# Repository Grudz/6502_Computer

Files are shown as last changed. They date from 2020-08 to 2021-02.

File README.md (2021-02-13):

# 6502_Computer
This repository stores everything for my 6502 project. This includes schematics, datasheets, C scripts, and assembly programs
.
[Ben Eater](https://www.youtube.com/playlist?list=PLowKtXNTBypFbtuVMUVXNR0z1mu7dp7eH) designed a custom clock module and 6502 computer on a breadboard. I expanded on that project, by combining those and turning them into a PCB.

-----
### Pretty dope red PCB I designed (4 layers:wink:)



### My Breadboard, not too shabby:sunglasses:

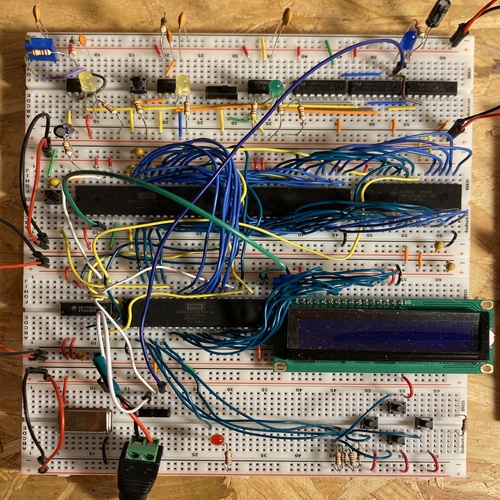
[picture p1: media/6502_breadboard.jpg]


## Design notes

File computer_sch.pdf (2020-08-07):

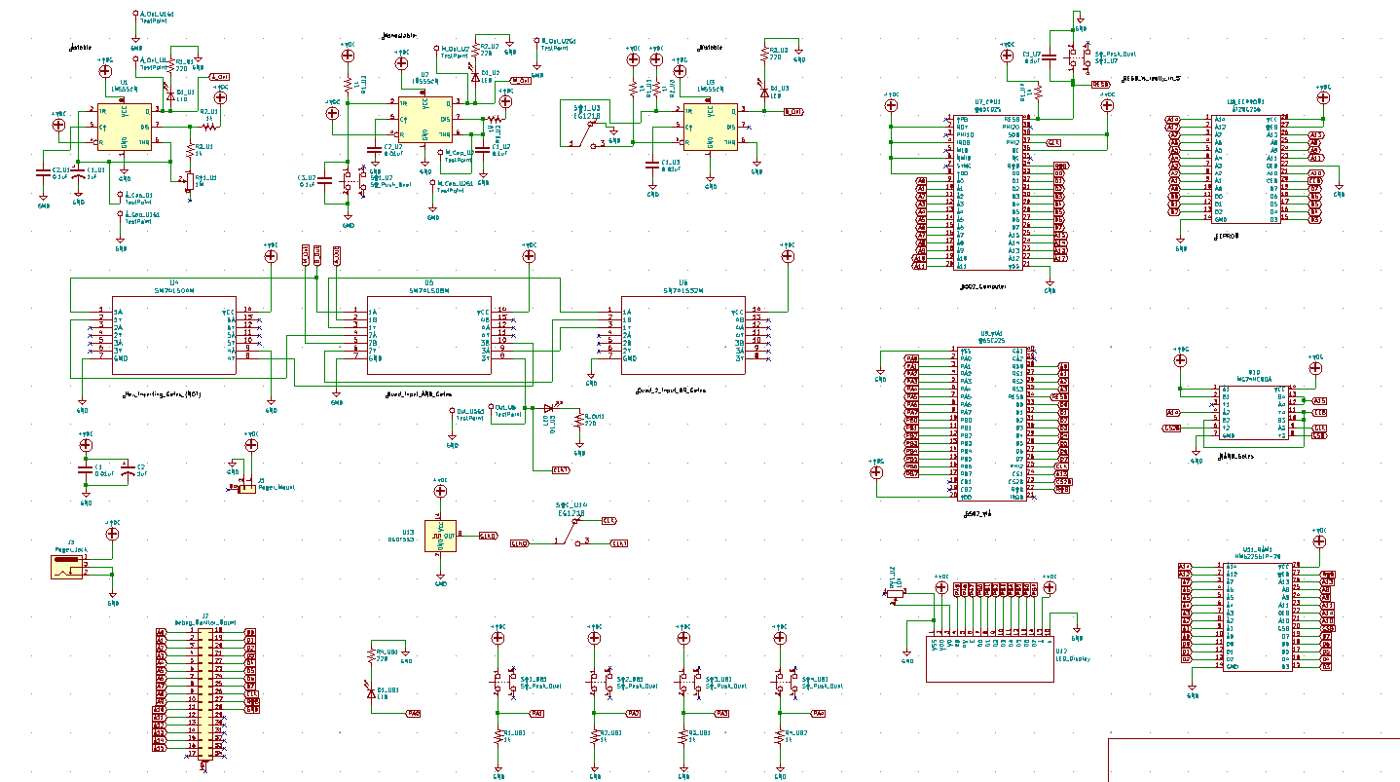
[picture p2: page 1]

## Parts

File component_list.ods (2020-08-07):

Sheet: Clock
Component | Package | Price [$] | Ordered | Delivered | Min Quantity | Footprint | Link to purchase
Ceramic Cap | THT | 17 | Yes | Yes | 5 | 157 | https://www.amazon.com/Hilitchi-Monolithic-Multilayer-Capacitors-Assortment/dp/B071P44QBH
Electrolytic Cap | THT | 15 | Yes | Yes | 1 | 59 | https://www.amazon.com/OCR-Electrolytic-Capacitor-Assortment-0-1uF%EF%BC%8D1000uF/dp/B01MSQOX0Q
Resistor | 1206 – SMD | 8 | Yes | Yes | 9 | 15 | https://www.amazon.com/McIgIcM-Resistor-ohm-10-Assorted-Samples/dp/B06XD8HPXS
Tactile Button | N/A | 0 | N/A | N/A | 1 | 87 | N/A
Switch | N/A | 3 | Yes | Yes | 1 | Custom | https://www.digikey.com/product-detail/en/EG1218/EG1903-ND/101726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
1M Pot | N/A | 10 | Yes | Yes | 1 | 39 | https://www.amazon.com/Twidec-Multiturn-Potentiometer-Assortment-3296W-13/dp/B07PYSR8SF
LED | N/A | 0 | N/A | N/A | 4 | 17 | N/A
SN74LS04 | N/A | 3 | Yes | Yes | 1 | Custom | https://www.mouser.com/ProductDetail/Texas-Instruments/SN74LS04N?qs=spW5eSrOWB4DgGWIHPxzvg%3D%3D
SN74LS08 | N/A | 12 | Yes | Yes | 1 | Custom | https://www.amazon.com/SN74LS08N-SN74LS08-74LS08N-HD74LS08P-Original/dp/B07KPMXX4P
SN74LS32 | N/A | 3 | Yes | Yes | 1 | Custom | https://www.mouser.com/ProductDetail/Texas-Instruments/SN74LS32N?qs=q2XTDbzbm6DA9Mnew5GiLA%3D%3D
LM555CN | N/A | 3 | Yes | Yes | 3 | 30 | https://www.parts-express.com/lm555-timer-ic-(8-pin-dip)--lm555 | have confirmation email from “contact”. It’s been 10 days, call tomorrow the 23rd
Test Point | N/A | 10 | Yes | Yes | 6 | 12 | https://www.digikey.com/product-detail/en/keystone-electronics/5000/36-5000-ND/255326 | https://www.digikey.com/product-detail/en/keystone-electronics/5001/36-5001-ND/255327 | https://www.digikey.com/product-detail/en/keystone-electronics/5002/36-5002-ND/255328 | https://www.digikey.com/product-detail/en/keystone-electronics/5004/36-5004-ND/362669 | https://www.digikey.com/product-detail/en/keystone-electronics/5003/36-5003-ND/362668
DIP Sockets | N/A | 11 | Yes | Yes | 6 | Same Footprint | https://www.amazon.com/Glarks-122Pcs-Sockets-Adaptor-Assortment/dp/B01GOLSUAU
 |  |  |  |  |  |  |  | PCB holder | To-Do List
 |  |  |  |  |  |  |  | https://www.amazon.com/Aven-17010-Adjustable-Circuit-Holder/dp/B00Q2TTQEE?s=industrial | Add areas to prop PCB off the ground
PCB |  |  |  |  |  |  |  | $10.00 | Ordered
Ordered on JLC PCB, should arrive by Friday unless unexpected delays
Cost $23 |  |  |  |  |  |  |  | TOTAL
 |  |  |  |  |  |  |  | 140ish

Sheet: Computer
Component | Package | Price [$] | Ordered | Delivered | Quantity | Footprint | Link to purchase
Ceramic Cap | THT | 17 | N/A | N/A | 5 | 157 | https://www.amazon.com/Hilitchi-Monolithic-Multilayer-Capacitors-Assortment/dp/B071P44QBH
Electrolytic Cap | THT | 15 | N/A | N/A | 1 | 59 | https://www.amazon.com/OCR-Electrolytic-Capacitor-Assortment-0-1uF%EF%BC%8D1000uF/dp/B01MSQOX0Q
Resistor | 1206 – SMD | 8 | N/A | N/A | 9 | 15 | https://www.amazon.com/McIgIcM-Resistor-ohm-10-Assorted-Samples/dp/B06XD8HPXS
Tactile Button | N/A | 0 | N/A | N/A | 1 | 87 | N/A
Switch | N/A | 3 | N/A | N/A | 1 | Custom | https://www.digikey.com/product-detail/en/EG1218/EG1903-ND/101726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
1M/10k Pot | N/A | 10 | N/A | N/A | 1 | 39 | https://www.amazon.com/Twidec-Multiturn-Potentiometer-Assortment-3296W-13/dp/B07PYSR8SF
LED | N/A | 0 | N/A | N/A | 4 | 17 | N/A
SN74LS04 | N/A | 3 | N/A | N/A | 1 | Custom | https://www.mouser.com/ProductDetail/Texas-Instruments/SN74LS04N?qs=spW5eSrOWB4DgGWIHPxzvg%3D%3D
SN74LS08 | N/A | 12 | N/A | N/A | 1 | Custom | https://www.amazon.com/SN74LS08N-SN74LS08-74LS08N-HD74LS08P-Original/dp/B07KPMXX4P
SN74LS32 | N/A | 3 | N/A | N/A | 1 | Custom | https://www.mouser.com/ProductDetail/Texas-Instruments/SN74LS32N?qs=q2XTDbzbm6DA9Mnew5GiLA%3D%3D
LM555CN | N/A | 3 | N/A | N/A | 3 | 30 | https://www.parts-express.com/lm555-timer-ic-(8-pin-dip)--lm555
Test Point | N/A | 10 | N/A | N/A | 6 | 12 | https://www.digikey.com/product-detail/en/keystone-electronics/5000/36-5000-ND/255326 | https://www.digikey.com/product-detail/en/keystone-electronics/5001/36-5001-ND/255327 | https://www.digikey.com/product-detail/en/keystone-electronics/5002/36-5002-ND/255328 | https://www.digikey.com/product-detail/en/keystone-electronics/5004/36-5004-ND/362669 | https://www.digikey.com/product-detail/en/keystone-electronics/5003/36-5003-ND/362668
DIP Sockets | N/A | 11 | N/A | N/A | 6 | Same Footprint | https://www.amazon.com/Glarks-122Pcs-Sockets-Adaptor-Assortment/dp/B01GOLSUAU
74HC00 | N/A | 5 | yes | yes | 10 | Same as other logic | https://www.jameco.com/webapp/wcs/stores/servlet/ProductDisplay?productId=45161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
W65C02S | N/A | 14 | yes | yes | 2 | 134 | https://www.jameco.com/z/W65C02S6TPG-14-Western-Design-Center-MPU-8-Bit-14MHz-65KB-Memory-40-Pin-PDIP_2143638.html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
W65C22 | N/A | 14 | yes | yes | 2 | 134 | https://www.jameco.com/webapp/wcs/stores/servlet/ProductDisplay?productId=2143591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
AT28C256 | N/A | 14 | yes | yes | 2 | 121 | https://www.jameco.com/webapp/wcs/stores/servlet/ProductDisplay?productId=74843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
HM62256B | N/A | 8 | yes | yes | 2 | 121 | https://www.jameco.com/webapp/wcs/stores/servlet/ProductDisplay?productId=82472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
1Mhz Clock | N/A | 6 | yes | yes | 3 | 3 | https://www.jameco.com/webapp/wcs/stores/servlet/ProductDisplay?productId=27861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
Rubber Props | N/A | 4 | yes | yes | 1 | N/A | https://www.jameco.com/z/BS34BL12X25RP-Rubber-Feet-Adhesive-Cylindrical-Black-0-375-Inch-x-0-125-Inch-100-Piece-Pack-_2119718.html
Tactile Buttons | N/A | 3 | yes | yes | 10 | Same as above | https://www.jameco.com/webapp/wcs/stores/servlet/ProductDisplay?productId=149948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
Female Headers | 2x34, 2.54mm | 3 | yes | yes | 3 | 208 | https://www.jameco.com/webapp/wcs/stores/servlet/ProductDisplay?productId=163862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
Male Headers | 2 Pin, 2.54mm | 1 | yes | yes | 10 | 4 | https://www.jameco.com/z/7000-1X2SG-R-Connector-Unshrouded-Header-Male-2-Position-0-100-2-54mm-Solder-Straight-Th_108338.html
Power Adapter | 2.5mm | 3 | yes | yes | 5 | 6 | https://www.jameco.com/webapp/wcs/stores/servlet/ProductDisplay?productId=2168122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 |  |  | (Ordered 15.24mm in 28pin dip sockets)
 |  |  |  |  |  |  |  | TOTAL | 120 + PCB
 |  |  |  |  |  |  |  | order number #20659175
 |  |  |  |  |  |  |  | Expected July 17th
PCB |  |  |  |  |  |  |  |  |  |  | Ordered another 2.1mmx5mm power adapter and barrel jack pcb mounts plus some wire for fun
Ordered on JLC PCB, should arrive by Friday unless unexpected delays |  |  |  |  |  |  |  |  |  |  | PCB ordered on July 21st
Cost $23
 |  |  |  |  | need new power adapater, prolly 2.1mm, but consider USBA
 |  |  |  |  | need pcb flux cleaner

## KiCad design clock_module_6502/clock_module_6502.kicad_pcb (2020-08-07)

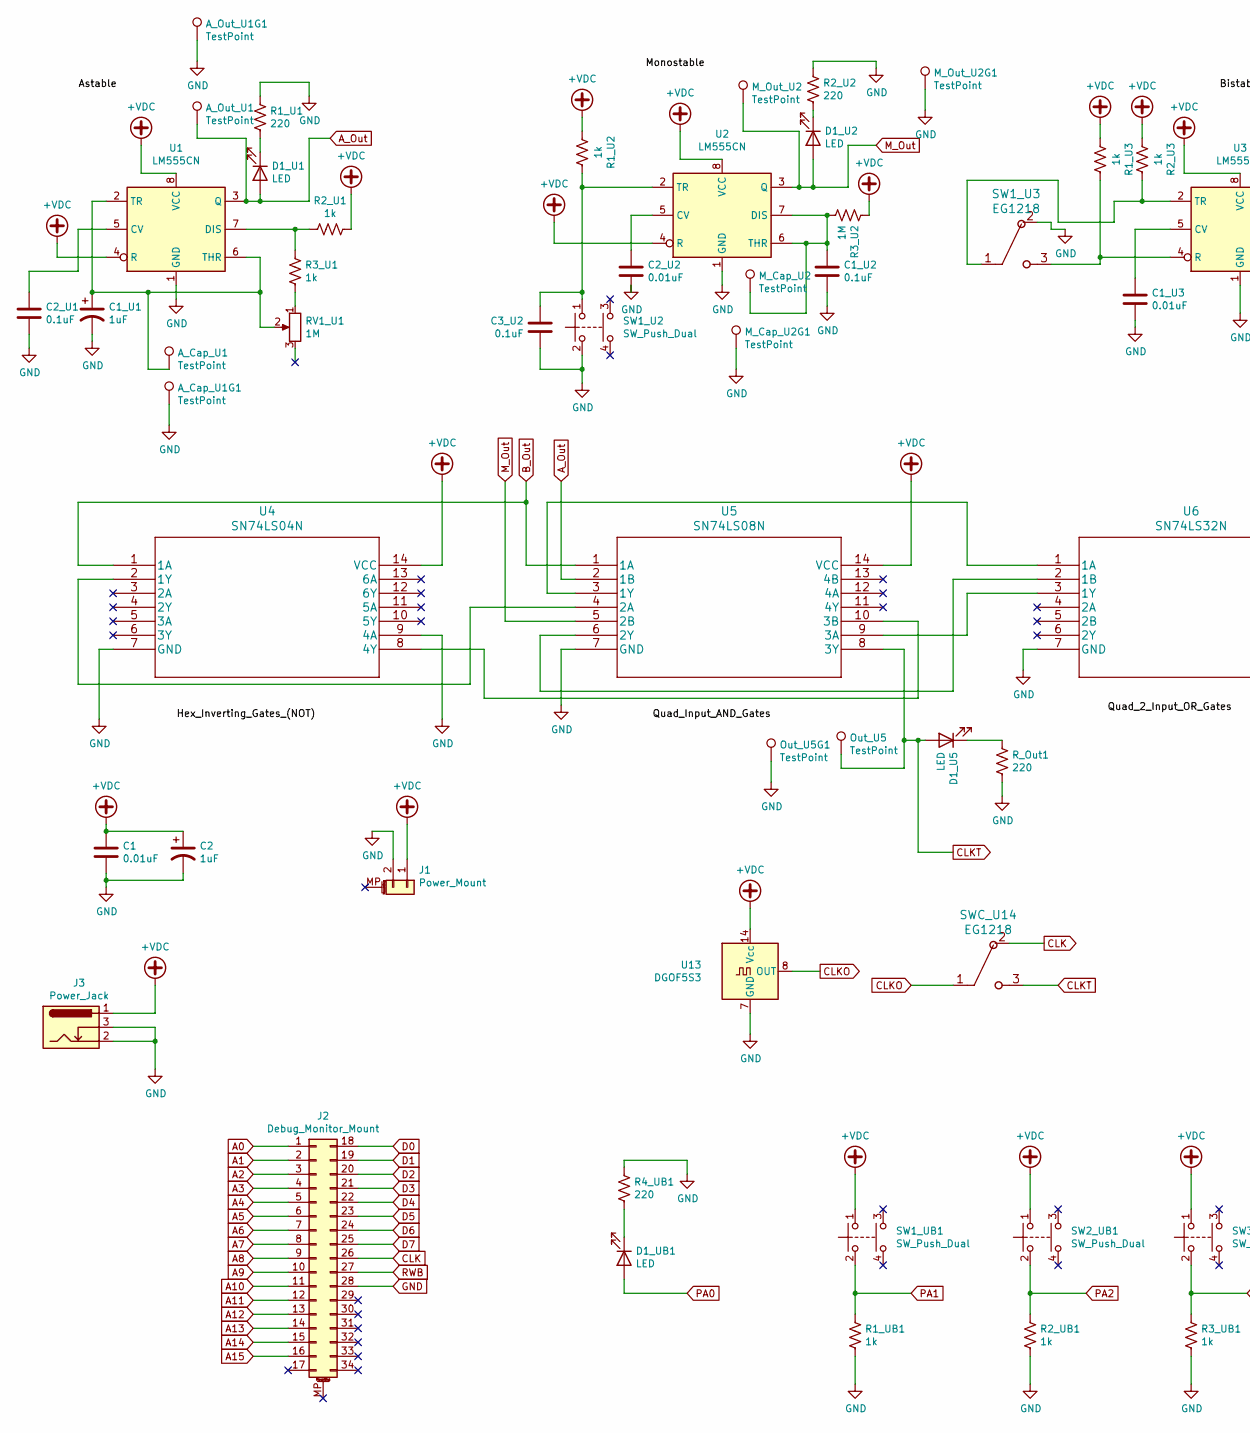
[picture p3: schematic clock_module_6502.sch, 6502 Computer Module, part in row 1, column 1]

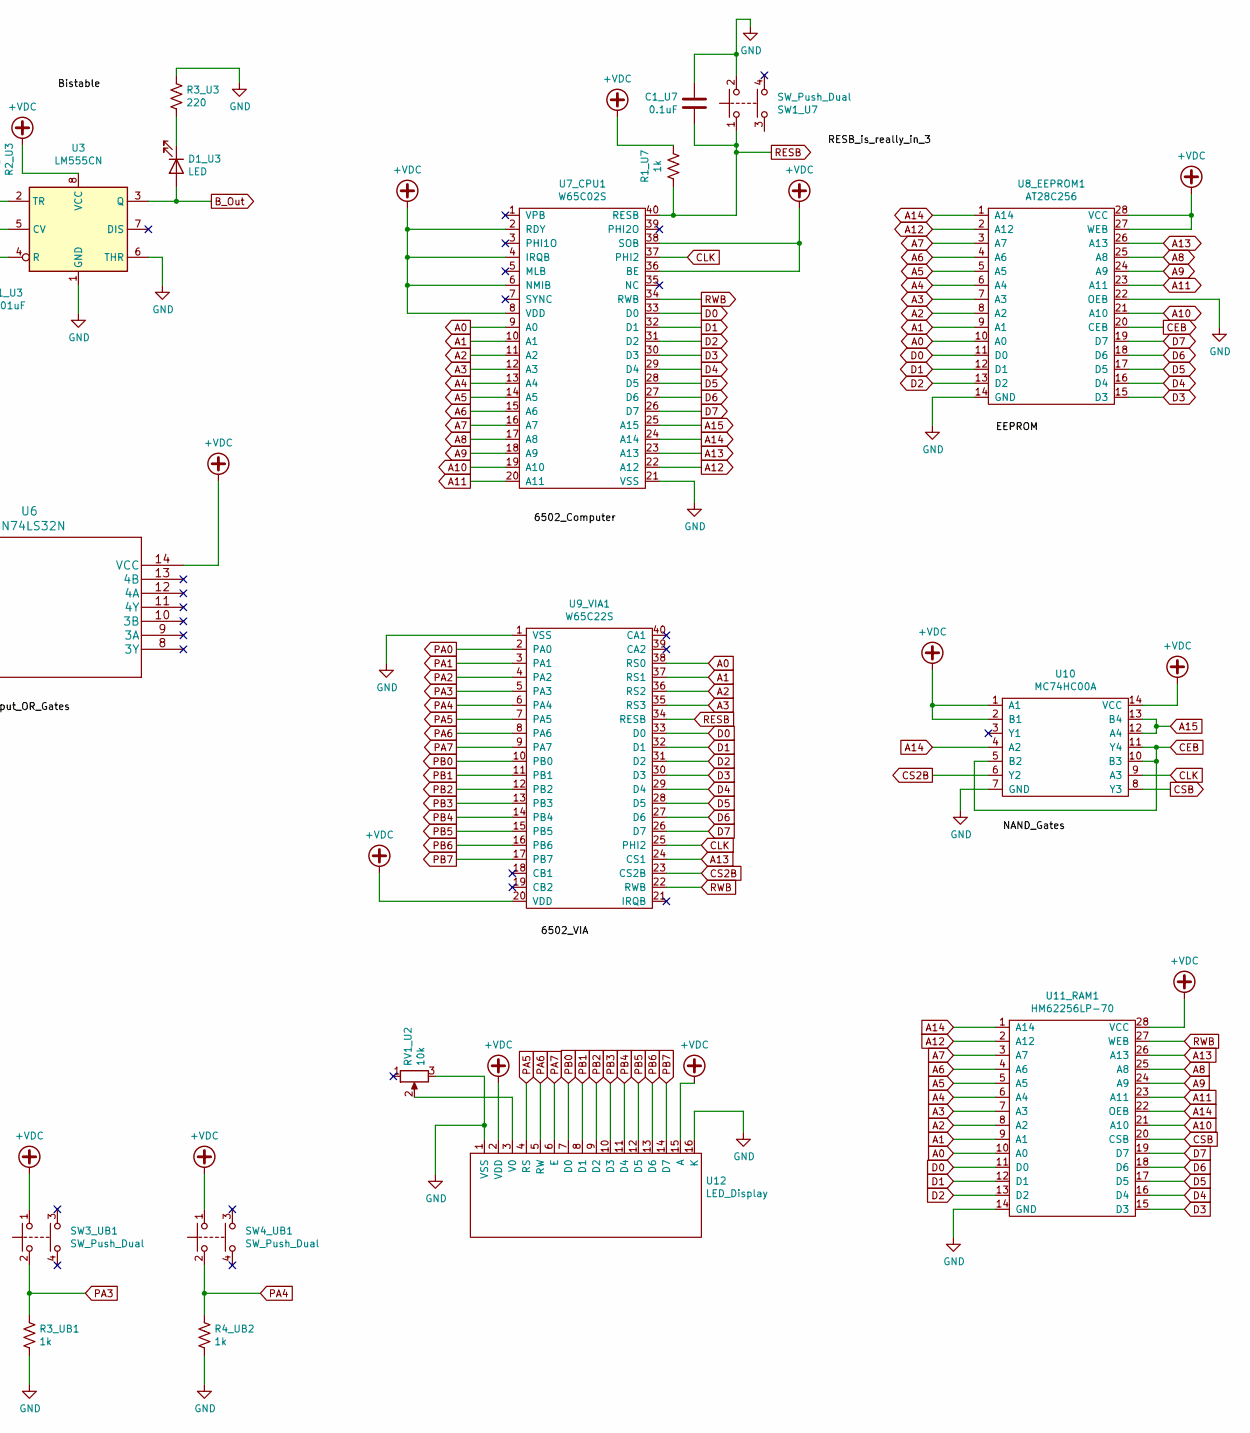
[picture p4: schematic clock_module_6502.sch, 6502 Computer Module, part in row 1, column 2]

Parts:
A_Cap_U1, A_Cap_U1G1: TestPoint; TestPoint_Keystone_5000-5004_Miniature
A_Out_U1, A_Out_U1G1: TestPoint; TestPoint_Keystone_5000-5004_Miniature
C1, C1_U3, C2_U2: 0.01uF; C_Disc_D7.5mm_W5.0mm_P5.00mm
C1_U1, C2: 1uF; CP_Radial_D5.0mm_P2.50mm
C1_U2, C1_U7, C2_U1, C3_U2: 0.1uF; C_Disc_D7.5mm_W5.0mm_P5.00mm
D1_U1, D1_U2, D1_U3, D1_U5, D1_UB1: LED; LED_D3.0mm_FlatTop
J1: Power_Mount; PinHeader_1x02_P2.54mm_Vertical
J2: Debug_Monitor_Mount; PinHeader_2x17_P2.54mm_Vertical
J3: Power_Jack; BarrelJack_Horizontal
M_Cap_U2, M_Cap_U2G1: TestPoint; TestPoint_Keystone_5000-5004_Miniature
M_Out_U2, M_Out_U2G1: TestPoint; TestPoint_Keystone_5000-5004_Miniature
Out_U5, Out_U5G1: TestPoint; TestPoint_Keystone_5000-5004_Miniature
R1_U1, R2_U2, R3_U3, R4_UB1: 220; R_1206_3216Metric_Pad1.42x1.75mm_HandSolder
R1_U2, R1_U3, R1_U7, R1_UB1, R2_U1, R2_U3, R2_UB1, R3_U1, R3_UB1, R4_UB2: 1k; R_1206_3216Metric_Pad1.42x1.75mm_HandSolder
R3_U2: 1M; R_1206_3216Metric_Pad1.42x1.75mm_HandSolder
RV1_U1: 1M; Potentiometer_Bourns_3296W_Vertical
RV1_U2: 10k; Potentiometer_Bourns_3296W_Vertical
R_Out1: 220; R_1206_3216Metric_Pad1.42x1.75mm_HandSolder
SW1_U2, SW1_U7, SW1_UB1, SW2_UB1, SW3_UB1, SW4_UB1: SW_Push_Dual; SW_Tactile_Straight_KSL0Axx1LFTR
SW1_U3: EG1218
SWC_U14: EG1218
U1, U2, U3: LM555CN; DIP-8_W7.62mm
U4: SN74LS04N; SN74LS32N
U5: SN74LS08N; SN74LS32N
U6: SN74LS32N
U7_CPU1: W65C02S; DIP-40_W15.24mm_Socket
U8_EEPROM1: AT28C256; DIP-28_W15.24mm_Socket
U9_VIA1: W65C22S; DIP-40_W15.24mm_Socket
U10: MC74HC00A; SN74LS32N
U11_RAM1: HM62256LP-70; DIP-28_W15.24mm_Socket
U12: LED_Display; WC1602A
U13: DGOF5S3; Oscillator_DIP-14

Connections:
+VDC: C1.1, C2.1, J1.1, J3.1, R1_U2.2, R1_U3.2, R1_U7.1, R2_U1.1, R2_U3.2, R3_U2.2, SW1_UB1.1, SW2_UB1.1, SW3_UB1.1, SW4_UB1.1, U1.4 (R), U1.8 (VCC), U2.4 (R), U2.8 (VCC), U3.8 (VCC), U4.14 (VCC), U5.14 (VCC), U6.14 (VCC), U7_CPU1.2 (RDY), U7_CPU1.4 (IRQB), U7_CPU1.6 (NMIB), U7_CPU1.8 (VDD), U7_CPU1.36 (BE), U7_CPU1.38 (SOB), U8_EEPROM1.27 (WEB), U8_EEPROM1.28 (VCC), U9_VIA1.20 (VDD), U10.1 (A1), U10.2 (B1), U10.14 (VCC), U11_RAM1.28 (VCC), U12.2 (VDD), U12.15 (A), U13.14 (Vcc)
A0: J2.1, U7_CPU1.9 (A0), U8_EEPROM1.10 (A0), U9_VIA1.38 (RS0), U11_RAM1.10 (A0)
A1: J2.2, U7_CPU1.10 (A1), U8_EEPROM1.9 (A1), U9_VIA1.37 (RS1), U11_RAM1.9 (A1)
A2: J2.3, U7_CPU1.11 (A2), U8_EEPROM1.8 (A2), U9_VIA1.36 (RS2), U11_RAM1.8 (A2)
A3: J2.4, U7_CPU1.12 (A3), U8_EEPROM1.7 (A3), U9_VIA1.35 (RS3), U11_RAM1.7 (A3)
A4: J2.5, U7_CPU1.13 (A4), U8_EEPROM1.6 (A4), U11_RAM1.6 (A4)
A5: J2.6, U7_CPU1.14 (A5), U8_EEPROM1.5 (A5), U11_RAM1.5 (A5)
A6: J2.7, U7_CPU1.15 (A6), U8_EEPROM1.4 (A6), U11_RAM1.4 (A6)
A7: J2.8, U7_CPU1.16 (A7), U8_EEPROM1.3 (A7), U11_RAM1.3 (A7)
A8: J2.9, U7_CPU1.17 (A8), U8_EEPROM1.25 (A8), U11_RAM1.25 (A8)
A9: J2.10, U7_CPU1.18 (A9), U8_EEPROM1.24 (A9), U11_RAM1.24 (A9)
A10: J2.11, U7_CPU1.19 (A10), U8_EEPROM1.21 (A10), U11_RAM1.21 (A10)
A11: J2.12, U7_CPU1.20 (A11), U8_EEPROM1.23 (A11), U11_RAM1.23 (A11)
A12: J2.13, U7_CPU1.22 (A12), U8_EEPROM1.2 (A12), U11_RAM1.2 (A12)
A13: J2.14, U7_CPU1.23 (A13), U8_EEPROM1.26 (A13), U9_VIA1.24 (CS1), U11_RAM1.26 (A13)
A14: J2.15, U7_CPU1.24 (A14), U8_EEPROM1.1 (A14), U10.4 (A2), U11_RAM1.1 (A14), U11_RAM1.22 (OEB)
A15: J2.16, U7_CPU1.25 (A15), U10.12 (A4), U10.13 (B4)
A_Out: A_Out_U1.1, D1_U1.2 (A), U1.3 (Q), U5.2 (1B)
B_Out: D1_U3.2 (A), U3.3 (Q), U4.1 (1A), U5.1 (1A)
CEB: U8_EEPROM1.20 (CEB), U10.5 (B2), U10.10 (B3), U10.11 (Y4)
CLK: J2.26, SWC_U14.2, U7_CPU1.37 (PHI2), U9_VIA1.25 (PHI2), U10.9 (A3)
CLKO: SWC_U14.1, U13.8 (OUT)
CLKT: D1_U5.2 (A), Out_U5.1, SWC_U14.3, U5.8 (3Y)
CS2B: U9_VIA1.23 (CS2B), U10.6 (Y2)
CSB: U10.8 (Y3), U11_RAM1.20 (CSB)
D0: J2.18, U7_CPU1.33 (D0), U8_EEPROM1.11 (D0), U9_VIA1.33 (D0), U11_RAM1.11 (D0)
D1: J2.19, U7_CPU1.32 (D1), U8_EEPROM1.12 (D1), U9_VIA1.32 (D1), U11_RAM1.12 (D1)
D2: J2.20, U7_CPU1.31 (D2), U8_EEPROM1.13 (D2), U9_VIA1.31 (D2), U11_RAM1.13 (D2)
D3: J2.21, U7_CPU1.30 (D3), U8_EEPROM1.15 (D3), U9_VIA1.30 (D3), U11_RAM1.15 (D3)
D4: J2.22, U7_CPU1.29 (D4), U8_EEPROM1.16 (D4), U9_VIA1.29 (D4), U11_RAM1.16 (D4)
D5: J2.23, U7_CPU1.28 (D5), U8_EEPROM1.17 (D5), U9_VIA1.28 (D5), U11_RAM1.17 (D5)
D6: J2.24, U7_CPU1.27 (D6), U8_EEPROM1.18 (D6), U9_VIA1.27 (D6), U11_RAM1.18 (D6)
D7: J2.25, U7_CPU1.26 (D7), U8_EEPROM1.19 (D7), U9_VIA1.26 (D7), U11_RAM1.19 (D7)
GND: A_Cap_U1G1.1, A_Out_U1G1.1, C1.2, C1_U1.2, C1_U2.2, C1_U3.2, C1_U7.1, C2.2, C2_U1.2, C2_U2.2, C3_U2.2, J1.2, J2.28, J3.2, J3.3, M_Cap_U2G1.1, M_Out_U2G1.1, Out_U5G1.1, R1_U1.2, R1_UB1.1, R2_U2.2, R2_UB1.1, R3_U3.2, R3_UB1.1, R4_UB1.2, R4_UB2.1, RV1_U2.3, R_Out1.1, SW1_U2.2, SW1_U3.2, SW1_U7.2, U1.1 (GND), U2.1 (GND), U3.1 (GND), U3.6 (THR), U4.7 (GND), U4.9 (4A), U5.7 (GND), U6.7 (GND), U7_CPU1.21 (VSS), U8_EEPROM1.14 (GND), U8_EEPROM1.22 (OEB), U9_VIA1.1 (VSS), U10.7 (GND), U11_RAM1.14 (GND), U12.1 (VSS), U12.16 (K), U13.7 (GND)
M_Out: D1_U2.2 (A), M_Out_U2.1, U2.3 (Q), U5.5 (2B)
unnamed: A_Cap_U1.1, C1_U1.1, RV1_U1.2, U1.2 (TR), U1.6 (THR)
unnamed: C1_U2.1, M_Cap_U2.1, R3_U2.1, U2.6 (THR), U2.7 (DIS)
unnamed: C1_U3.1, U3.5 (CV)
unnamed: C2_U1.1, U1.5 (CV)
unnamed: C2_U2.1, U2.5 (CV)
unnamed: C3_U2.1, R1_U2.1, SW1_U2.1, U2.2 (TR)
unnamed: D1_U1.1 (K), R1_U1.1
unnamed: D1_U2.1 (K), R2_U2.1
unnamed: D1_U3.1 (K), R3_U3.1
unnamed: D1_U5.1 (K), R_Out1.2
unnamed: D1_UB1.1 (K), R4_UB1.1
unnamed: R1_U3.1, SW1_U3.3, U3.4 (R)
unnamed: R2_U1.2, R3_U1.2, U1.7 (DIS)
unnamed: R2_U3.1, SW1_U3.1, U3.2 (TR)
unnamed: R3_U1.1, RV1_U1.1
unnamed: RV1_U2.2, U12.3 (V0)
unnamed: U4.2 (1Y), U5.4 (2A)
unnamed: U4.8 (4Y), U5.10 (3B)
unnamed: U5.3 (1Y), U6.1 (1A)
unnamed: U5.6 (2Y), U6.2 (1B)
unnamed: U5.9 (3A), U6.3 (1Y)
PA0: D1_UB1.2 (A), U9_VIA1.2 (PA0)
PA1: R1_UB1.2, SW1_UB1.2, U9_VIA1.3 (PA1)
PA2: R2_UB1.2, SW2_UB1.2, U9_VIA1.4 (PA2)
PA3: R3_UB1.2, SW3_UB1.2, U9_VIA1.5 (PA3)
PA4: R4_UB2.2, SW4_UB1.2, U9_VIA1.6 (PA4)
PA5: U9_VIA1.7 (PA5), U12.4 (RS)
PA6: U9_VIA1.8 (PA6), U12.5 (RW)
PA7: U9_VIA1.9 (PA7), U12.6 (E)
PB0: U9_VIA1.10 (PB0), U12.7 (D0)
PB1: U9_VIA1.11 (PB1), U12.8 (D1)
PB2: U9_VIA1.12 (PB2), U12.9 (D2)
PB3: U9_VIA1.13 (PB3), U12.10 (D3)
PB4: U9_VIA1.14 (PB4), U12.11 (D4)
PB5: U9_VIA1.15 (PB5), U12.12 (D5)
PB6: U9_VIA1.16 (PB6), U12.13 (D6)
PB7: U9_VIA1.17 (PB7), U12.14 (D7)
RESB: C1_U7.2, R1_U7.2, SW1_U7.1, U7_CPU1.40 (RESB), U9_VIA1.34 (RESB)
RWB: J2.27, U7_CPU1.34 (RWB), U9_VIA1.22 (RWB), U11_RAM1.27 (WEB)

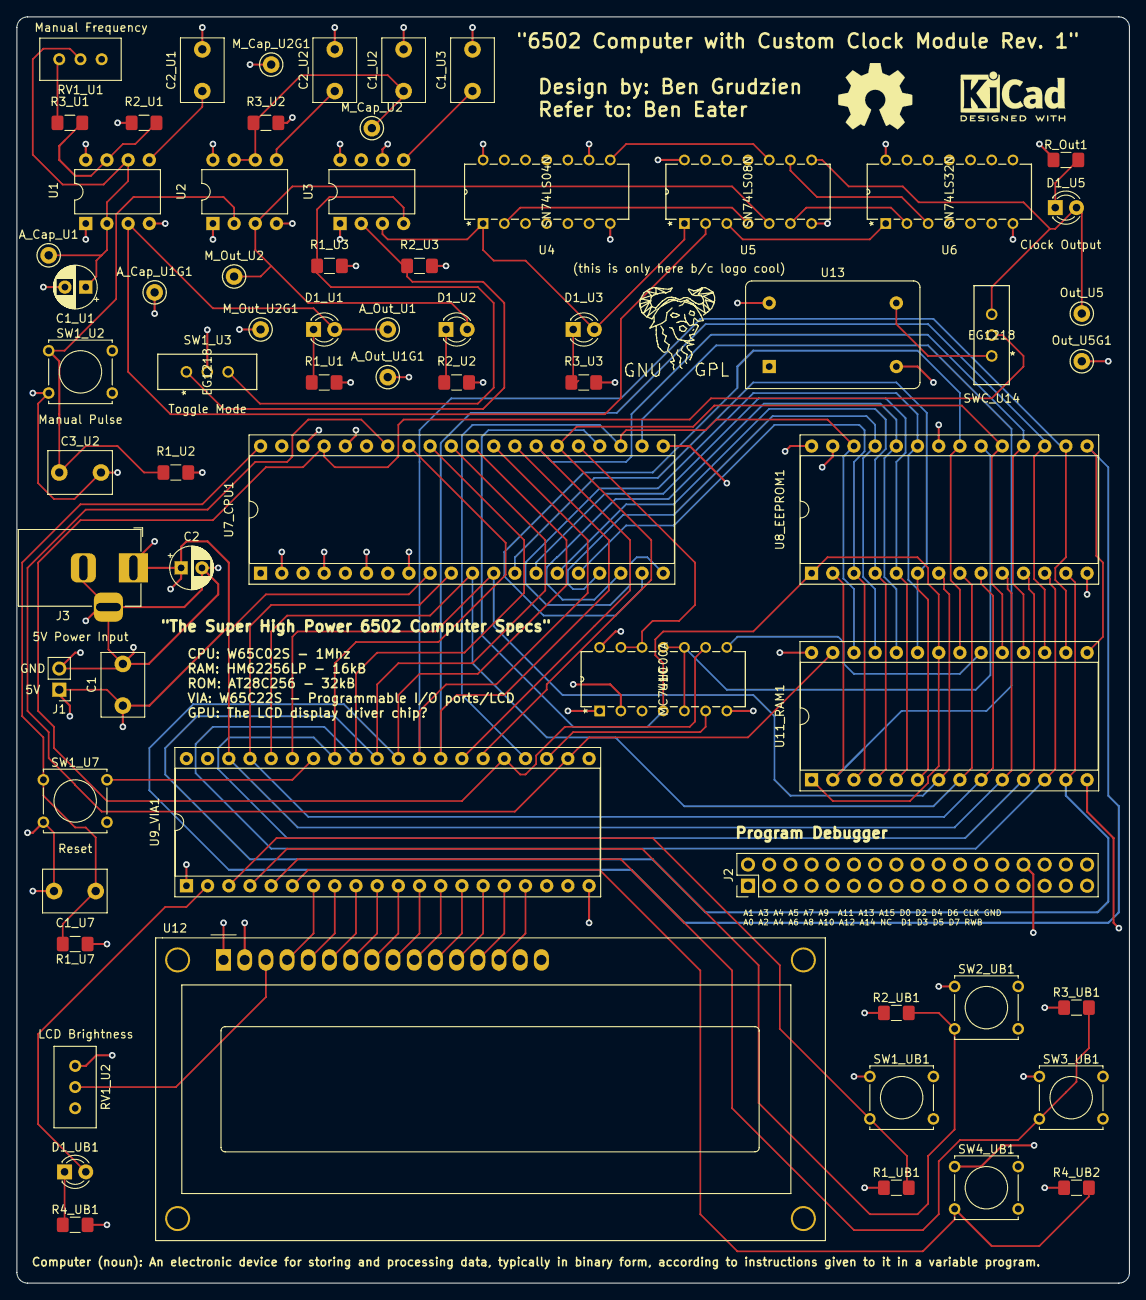
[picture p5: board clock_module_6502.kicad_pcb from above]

Board: 4 copper layers, 133.3 x 151.8 mm, 67 parts (0 on the bottom side), 74 nets.

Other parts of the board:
(this is only here b/c logo cool): Symbol_GNU-Logo_SilkscreenTop

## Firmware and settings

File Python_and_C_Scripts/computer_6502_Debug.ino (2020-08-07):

// By Ben Grudzien, refer to Ben Eater

const char ADDR[] = {22, 24, 26, 28, 30, 32, 34, 36, 38, 40, 42, 44, 46, 48, 50, 52}; // A0 to A15
const char DATA[] = {39, 41, 43, 45, 47, 49, 51, 53}; // D0 to D7
#define CLOCK 2 // Only some pins support interrupts
#define READ_WRITE 3 // Check data bus stats

void setup() {
  // put your setup code here, to run once:
  for (int n = 0; n < 16; n += 1){ // Address read
    pinMode(ADDR[n], INPUT);
  }
  for (int n = 0; n < 8; n += 1){ // Data read
    pinMode(DATA[n], INPUT);
  }  
  pinMode(CLOCK, INPUT);
  pinMode(READ_WRITE, INPUT);
  
  attachInterrupt(digitalPinToInterrupt(CLOCK), onClock, RISING); // This allows for single step
  
  Serial.begin(57600); // Standard baud rate
}

void onClock(){

   char output[15];
   
   unsigned int address = 0; // To get address as number to convert to hex or whatever
   for (int n = 0; n < 16; n += 1){
    int bit = digitalRead(ADDR[n]) ? 1 : 0; // If True 1, else 0
    Serial.print(bit);
    address = (address << 1) + bit; // Shifts to left
  }
   Serial.print("   "); 

   unsigned int data = 0;
   for (int n = 0; n < 8; n += 1){
    int bit = digitalRead(DATA[n]) ? 1 : 0; // If True 1, else 0
    Serial.print(bit);
    data = (data << 1) + bit;
  }  

  sprintf(output, "   %04x %c %02x", address, digitalRead(READ_WRITE) ? 'R' : 'W', data); // address = 4 digit hex, data = 2 digit hex
  Serial.println(output); // New line
}


void loop() {
  // put your main code here, to run repeatedly:

}

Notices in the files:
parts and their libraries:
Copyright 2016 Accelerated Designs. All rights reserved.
